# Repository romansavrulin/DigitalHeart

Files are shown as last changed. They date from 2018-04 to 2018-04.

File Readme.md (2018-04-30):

# RDC1-0009, Цифровое сердце

Это цифровое, светодиодное сердце будет отличным подарком девушке ко Дню Влюбленных, 8 Марта, или на День рождения.
21 светодиод расположены по периметру печатной платы в виде сердца. Все они управляются микроконтроллером ATmega328. В демонстрационном скетче прописаны несколько эффектов оживляющих сердце. Скетч загружается с помощью любого контроллера Arduino. Но главная изюминка это вибромоторчик от смартфона расположенный на тыльной стороне. Он создает эффект бьющегося в такт световым эффектам сердца. Скетч легко изменить, если вы придумаете новые световые эффекты и частоту стука сердца. 
На тыльной стороне сердца есть зарядное устройство для Li-ion аккумуляторов, которое будет подзаряжать ваше сердце через порт Mini USB. Схема зарядного устройства собрана на микросхеме MCP73831T. Схема включения стандартная из описания на микросхему.
Все детали проекта открыты для свободного использования. Проект созданный в KiCAD можно скачать в приложении. Программу скачивайте в разделе «Скетч – код программы».

## Внешний вид устройства

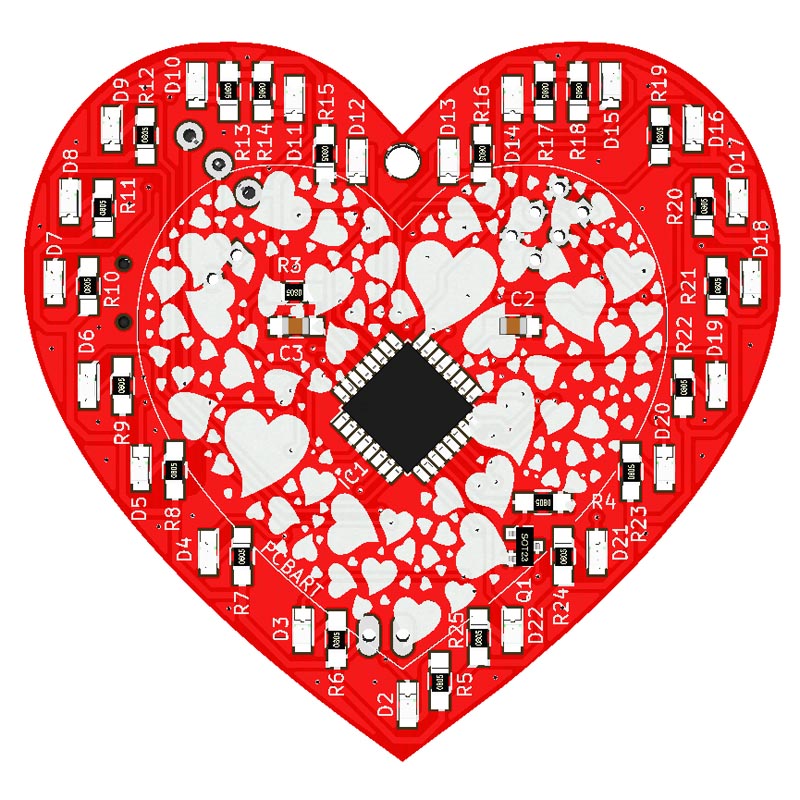
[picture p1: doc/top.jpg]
TOP


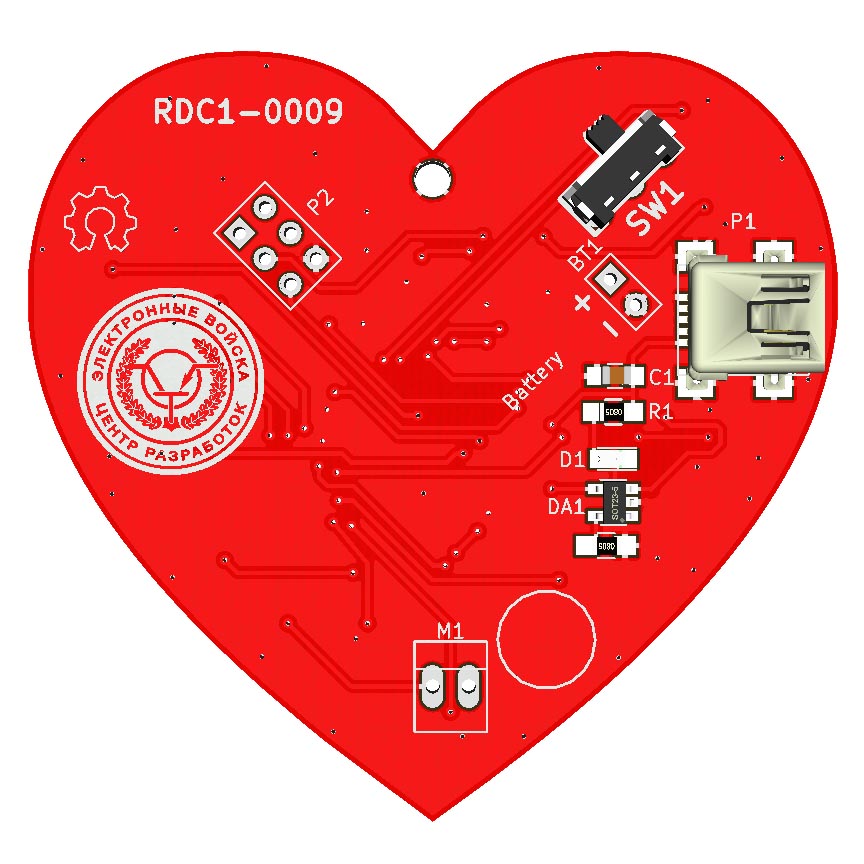
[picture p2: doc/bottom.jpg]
BOTTOM


## Технические параметры

Размер - 50 х 50 мм.
Источник питания – Li-Ion или Li-Pol аккумулятор 3,7В

## Programmer wiring

| Nano pins | NANO ISP PIN | Nano net | Target Net | Target Pin |
|-----|-----|-----|-----|----|
| D12 | 1 | MOSI | MISO | 1 |
| 5V  | 2 | 5V | 5V | 2 |
| D13 | 3 | SCK | SCK  | 3 |
| D11 | 4 | MISO | MOSI | 4 |
| D10 | N/A, USE D10 | TARGET_RST | RST | 5  |
| GND | 6 | GND | GND  | 6 |

## Troubleshooting

If you get slow effects, it's wrong FUSE configuration. Try to run 

```
"C:\Program Files (x86)\Arduino\hardware\tools\avr/bin/avrdude" "-CC:\Program Files (x86)\Arduino\hardware\tools\avr/etc/avrdude.conf" -v -patmega168p -cstk500v1 -PCOM4 -b19200 -U lfuse:w:0xE2:m
```

from console

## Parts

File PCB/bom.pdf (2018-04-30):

количество | позиция | наименование номенклатуры | код номенклатуры
22 | D1 - D22 | KPT-2012SURCK, Светодиод красный 150мКд SMD | 498825037
1 | P1 | MiniUSB-A, Розетка 5-контактная SMD на плату | 587420270
3 | C1, C2,C3 | Кер.ЧИП конд. 0.1 мкФ Y5V 50В,+80-20%, 0805 | 642412305
1 | SW1 | SS12F27, Переключатель движковый | 826042990
1 | R2 | 0.125Вт 0805 2 кОм, 5%, Чип резистор (SMD) | 811944944
22 | R1, R5-R25 | 0.125Вт 0805 360 Ом, 1%, Чип резистор (SMD) | 9000079475
2 | R3, R4 | 0.125Вт 0805 10 кОм, 1%, Чип резистор (SMD) | 9000079514
1 | IC1 | ATmega168PA-AU | 9000105081
1 | DA1 | MCP73831T | 9000161965
1 | V.Motor | VIBRATING-MOTOR | 9000313207
1 | Q1 | BSS138, Транзистор, N-канал | 919815894
1 | | Печатная плата rdc1-0009 h | 9000327321

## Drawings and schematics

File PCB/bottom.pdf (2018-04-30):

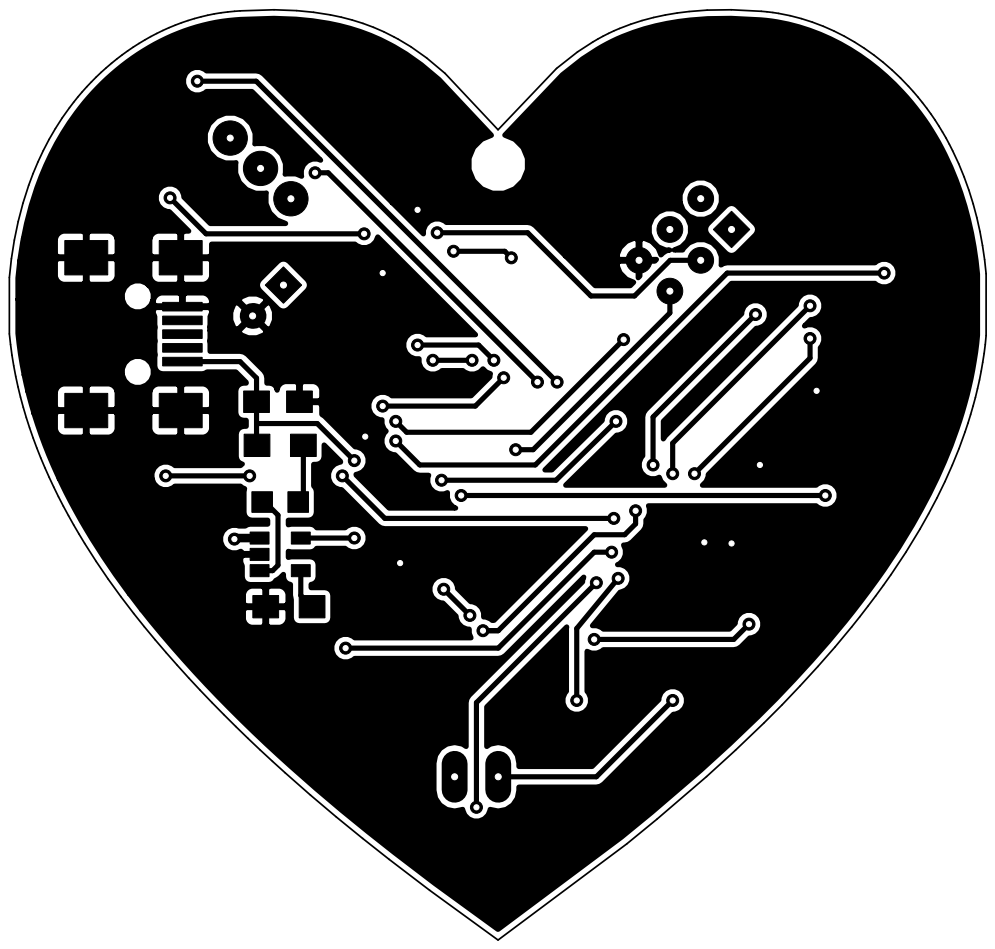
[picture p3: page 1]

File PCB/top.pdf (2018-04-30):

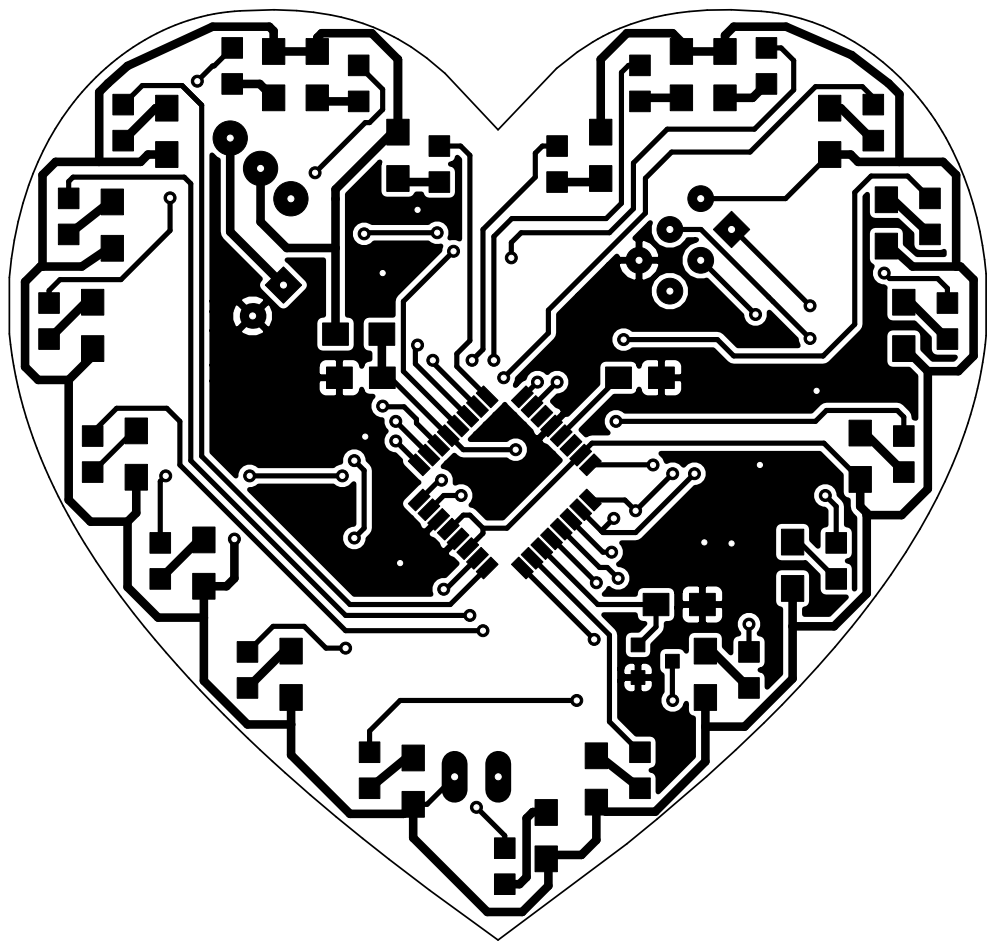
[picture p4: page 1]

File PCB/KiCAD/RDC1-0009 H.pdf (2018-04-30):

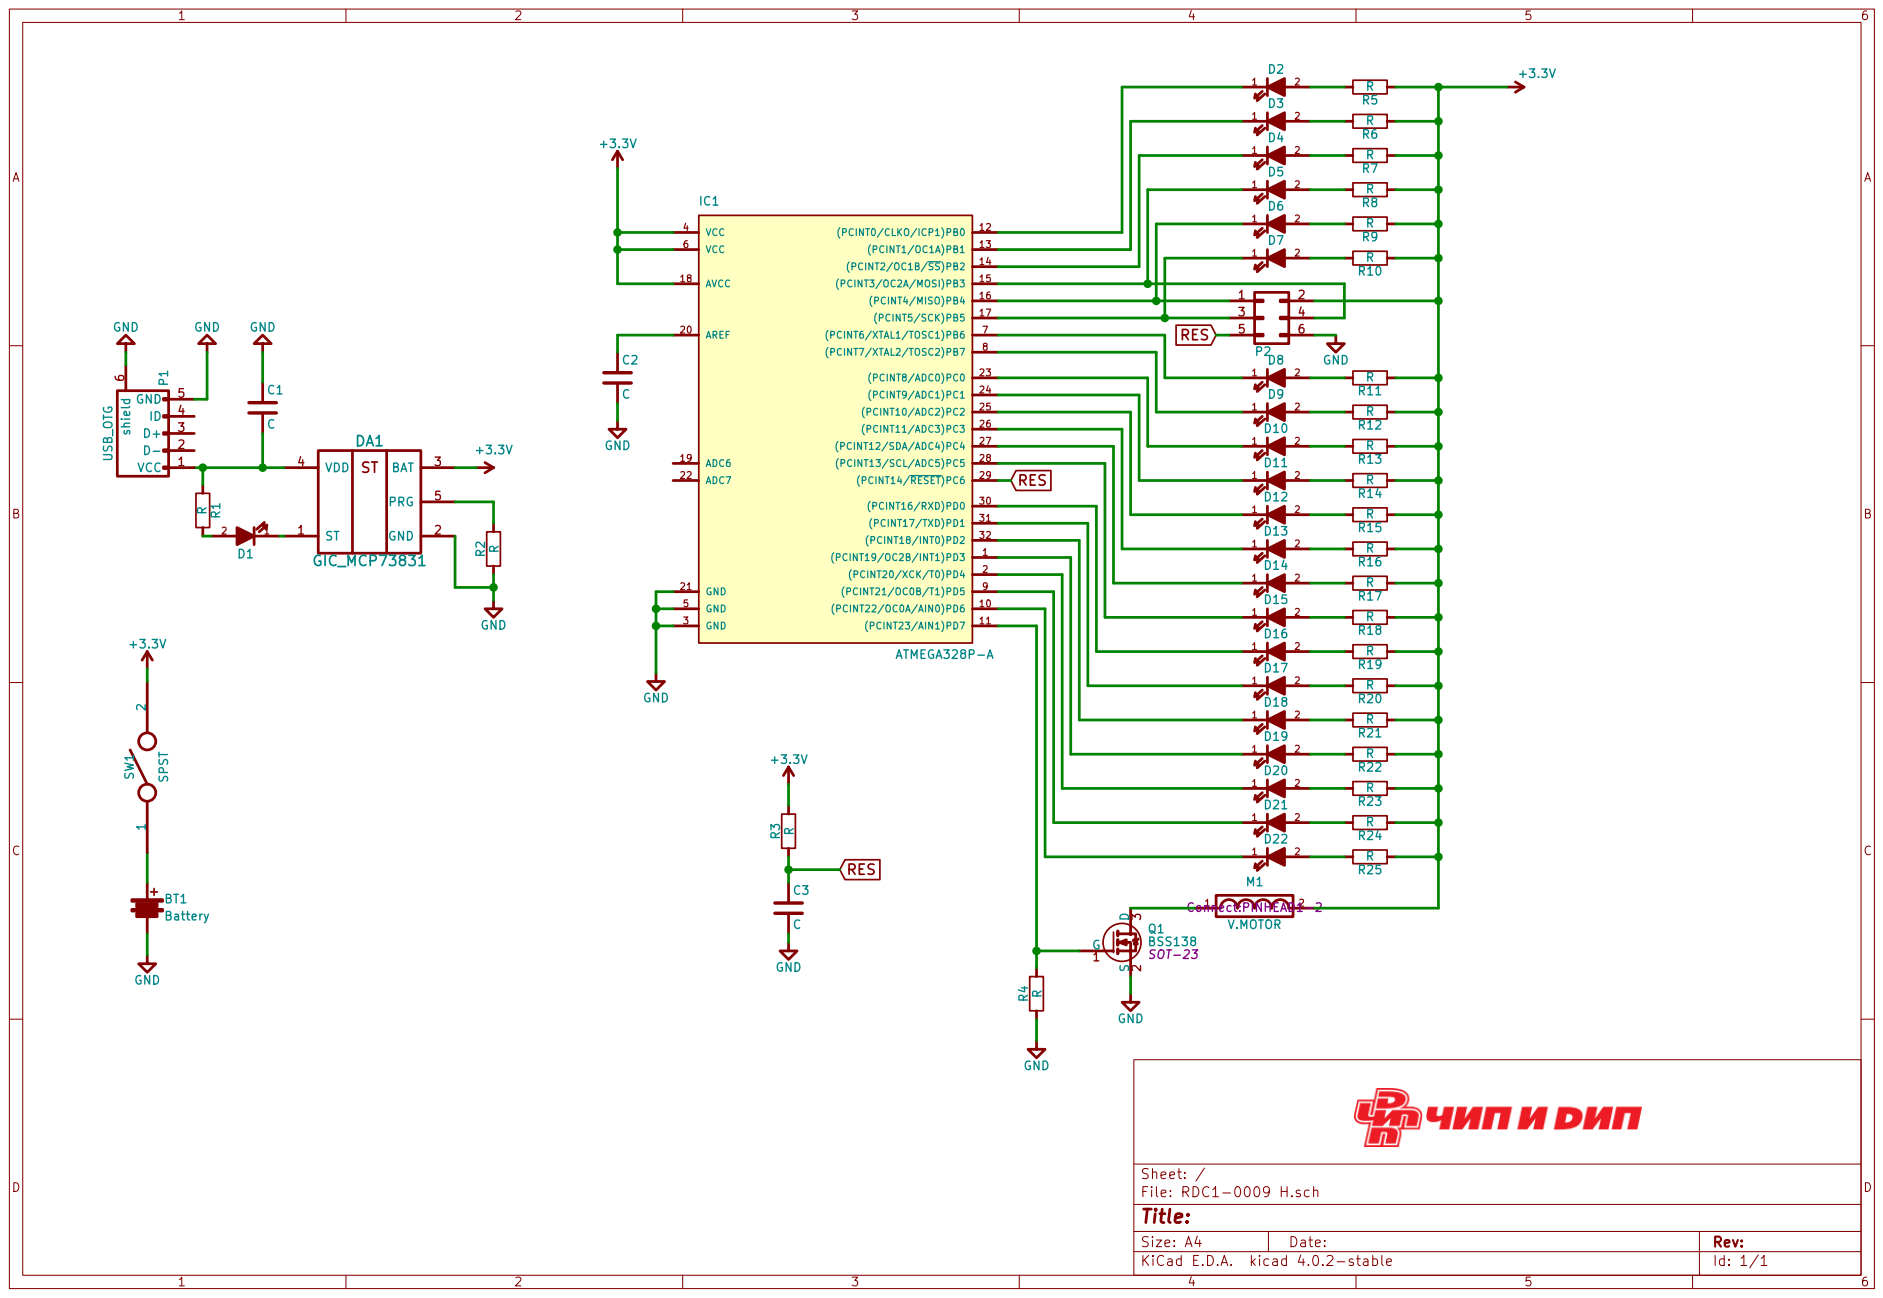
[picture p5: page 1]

Id: 1/1 Title: File: RDC1-0009 H.sch Sheet: /

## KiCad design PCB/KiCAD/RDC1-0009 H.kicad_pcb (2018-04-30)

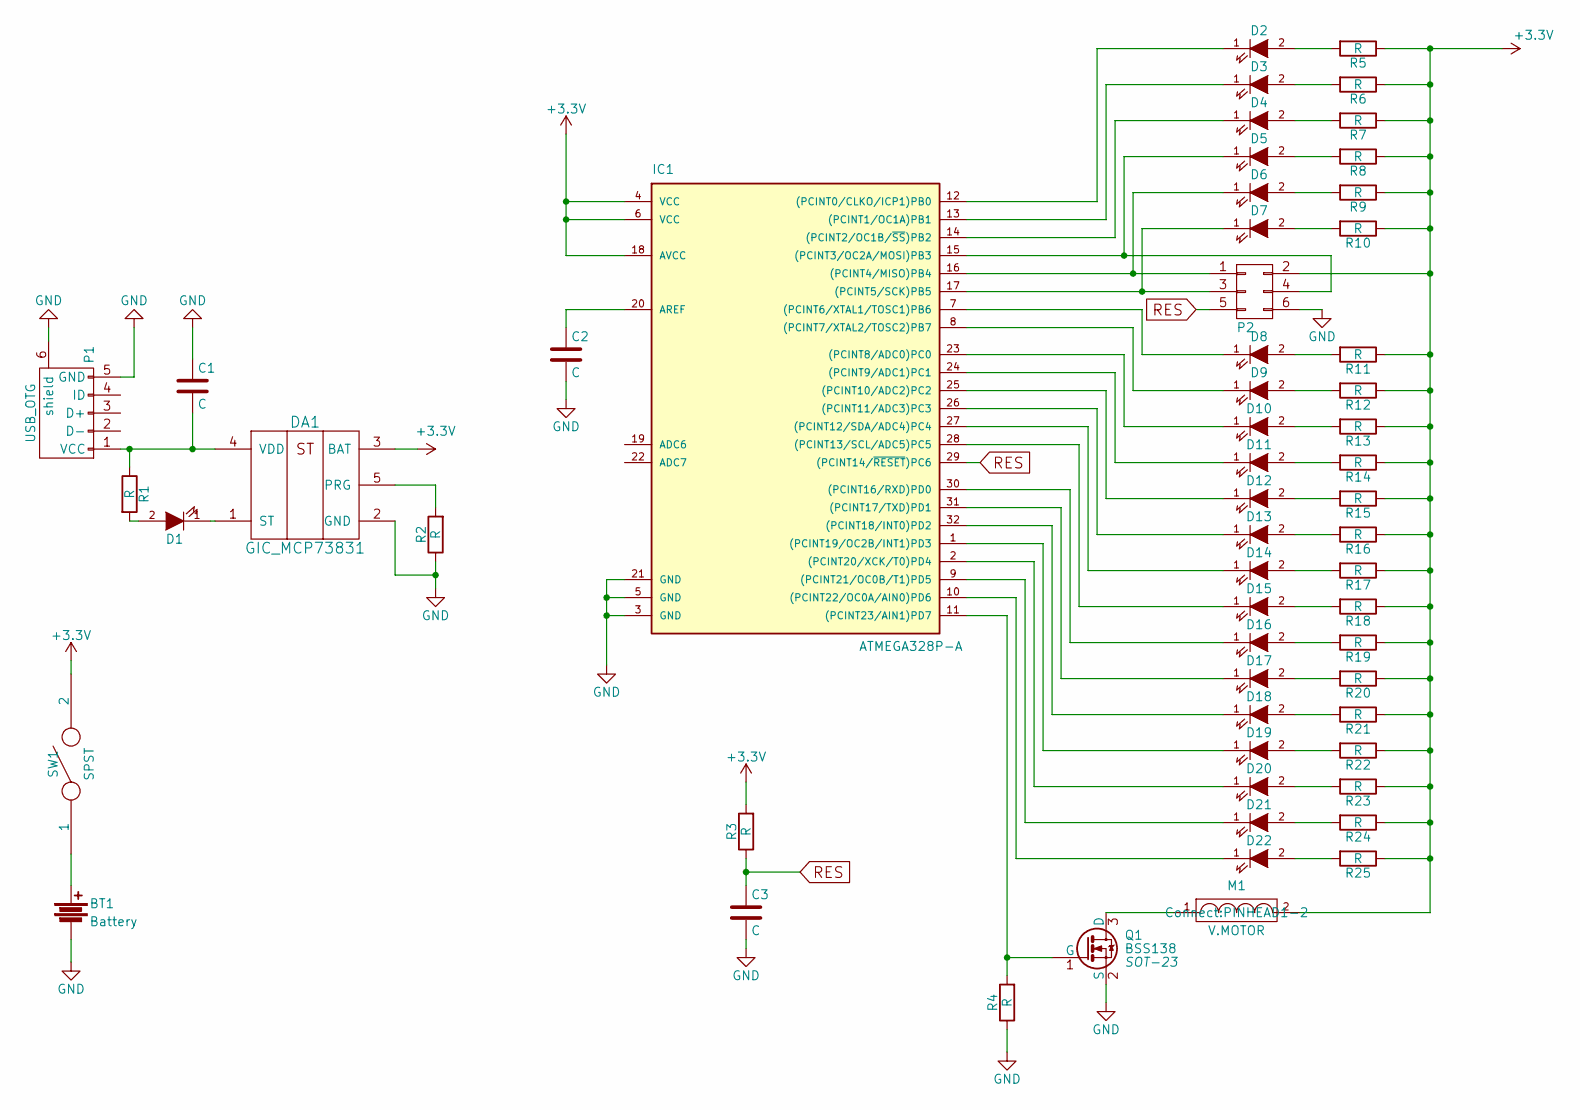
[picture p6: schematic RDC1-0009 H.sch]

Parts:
BT1: Battery; Pin_Header_Straight_1x02_mm
C1, C2, C3: C; C_0805_HandSoldering
D1, D2, D3, D4, D5, D6, D7, D8, D9, D10, D11, D12, D13, D14, D15, D16, D17, D18, D19, D20, D21, D22: LED; LED_0805
DA1: GIC_MCP73831; SOT-23-5_mm
IC1: ATMEGA328P-A; LQFP-32_7x7mm_Pitch0.8mm
M1: V.MOTOR; PINHEAD1-2
P1: USB_OTG; USB_Mini-B_mm
P2: CONN_02X03; Pin_Header_Straight_2x03_mm
Q1: BSS138; SOT-23
R1, R2, R3, R4, R5, R6, R7, R8, R9, R10, R11, R12, R13, R14, R15, R16, R17, R18, R19, R20, R21, R22, R23, R24, R25: R; R_0805_HandSoldering
SW1: SPST; SWITCH-mmp122-r

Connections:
+3V3: DA1.3 (BAT), IC1.4 (VCC), IC1.6 (VCC), IC1.18 (AVCC), M1.2, P2.2, R3.2, R5.1, R6.1, R7.1, R8.1, R9.1, R10.1, R11.1, R12.1, R13.1, R14.1, R15.1, R16.1, R17.1, R18.1, R19.1, R20.1, R21.1, R22.1, R23.1, R24.1, R25.1, SW1.2
GND: BT1.2, C1.1, C2.2, C3.2, DA1.2 (GND), IC1.3 (GND), IC1.5 (GND), IC1.21 (GND), P1.5 (GND), P1.6 (shield), P2.6, Q1.2 (S), R2.1, R4.1
unnamed: BT1.1, SW1.1
unnamed: C1.2, DA1.4 (VDD), P1.1 (VCC), R1.1
unnamed: C2.1, IC1.20 (AREF)
unnamed: D1.1 (K), DA1.1 (ST)
unnamed: D1.2 (A), R1.2
unnamed: D2.1 (K), IC1.12 ((PCINT0/CLKO/ICP1)PB0)
unnamed: D2.2 (A), R5.2
unnamed: D3.1 (K), IC1.13 ((PCINT1/OC1A)PB1)
unnamed: D3.2 (A), R6.2
unnamed: D4.1 (K), IC1.14 ((PCINT2/OC1B/~SS~)PB2)
unnamed: D4.2 (A), R7.2
unnamed: D5.1 (K), IC1.15 ((PCINT3/OC2A/MOSI)PB3), P2.4
unnamed: D5.2 (A), R8.2
unnamed: D6.1 (K), IC1.16 ((PCINT4/MISO)PB4), P2.1
unnamed: D6.2 (A), R9.2
unnamed: D7.1 (K), IC1.17 ((PCINT5/SCK)PB5), P2.3
unnamed: D7.2 (A), R10.2
unnamed: D8.1 (K), IC1.7 ((PCINT6/XTAL1/TOSC1)PB6)
unnamed: D8.2 (A), R11.2
unnamed: D9.1 (K), IC1.8 ((PCINT7/XTAL2/TOSC2)PB7)
unnamed: D9.2 (A), R12.2
unnamed: D10.1 (K), IC1.23 ((PCINT8/ADC0)PC0)
unnamed: D10.2 (A), R13.2
unnamed: D11.1 (K), IC1.24 ((PCINT9/ADC1)PC1)
unnamed: D11.2 (A), R14.2
unnamed: D12.1 (K), IC1.25 ((PCINT10/ADC2)PC2)
unnamed: D12.2 (A), R15.2
unnamed: D13.1 (K), IC1.26 ((PCINT11/ADC3)PC3)
unnamed: D13.2 (A), R16.2
unnamed: D14.1 (K), IC1.27 ((PCINT12/SDA/ADC4)PC4)
unnamed: D14.2 (A), R17.2
unnamed: D15.1 (K), IC1.28 ((PCINT13/SCL/ADC5)PC5)
unnamed: D15.2 (A), R18.2
unnamed: D16.1 (K), IC1.30 ((PCINT16/RXD)PD0)
unnamed: D16.2 (A), R19.2
unnamed: D17.1 (K), IC1.31 ((PCINT17/TXD)PD1)
unnamed: D17.2 (A), R20.2
unnamed: D18.1 (K), IC1.32 ((PCINT18/INT0)PD2)
unnamed: D18.2 (A), R21.2
unnamed: D19.1 (K), IC1.1 ((PCINT19/OC2B/INT1)PD3)
unnamed: D19.2 (A), R22.2
unnamed: D20.1 (K), IC1.2 ((PCINT20/XCK/T0)PD4)
unnamed: D20.2 (A), R23.2
unnamed: D21.1 (K), IC1.9 ((PCINT21/OC0B/T1)PD5)
unnamed: D21.2 (A), R24.2
unnamed: D22.1 (K), IC1.10 ((PCINT22/OC0A/AIN0)PD6)
unnamed: D22.2 (A), R25.2
unnamed: DA1.5 (PRG), R2.2
unnamed: IC1.11 ((PCINT23/AIN1)PD7), Q1.1 (G), R4.2
unnamed: M1.1, Q1.3 (D)
RES: C3.1, IC1.29 ((PCINT14/~RESET~)PC6), P2.5, R3.1

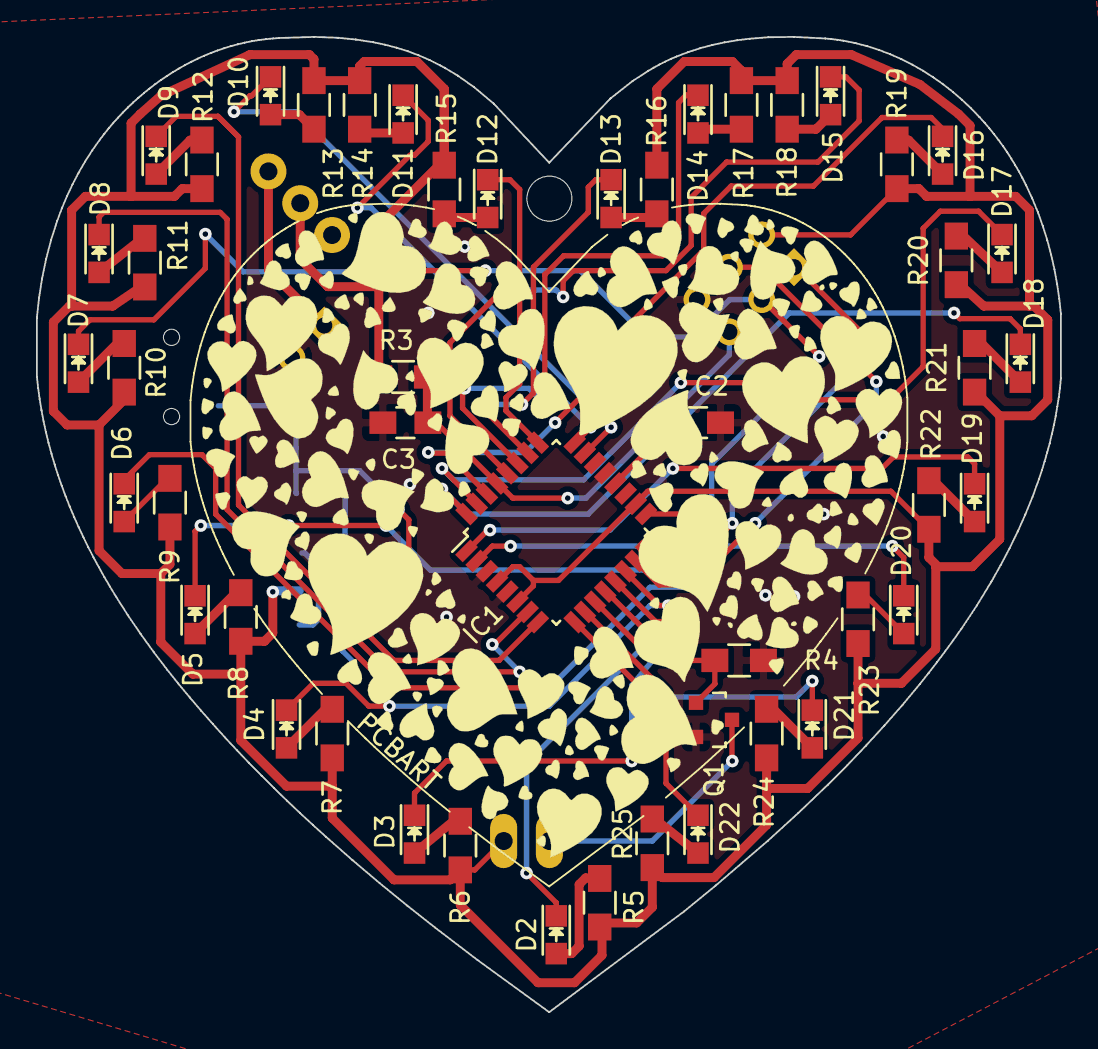
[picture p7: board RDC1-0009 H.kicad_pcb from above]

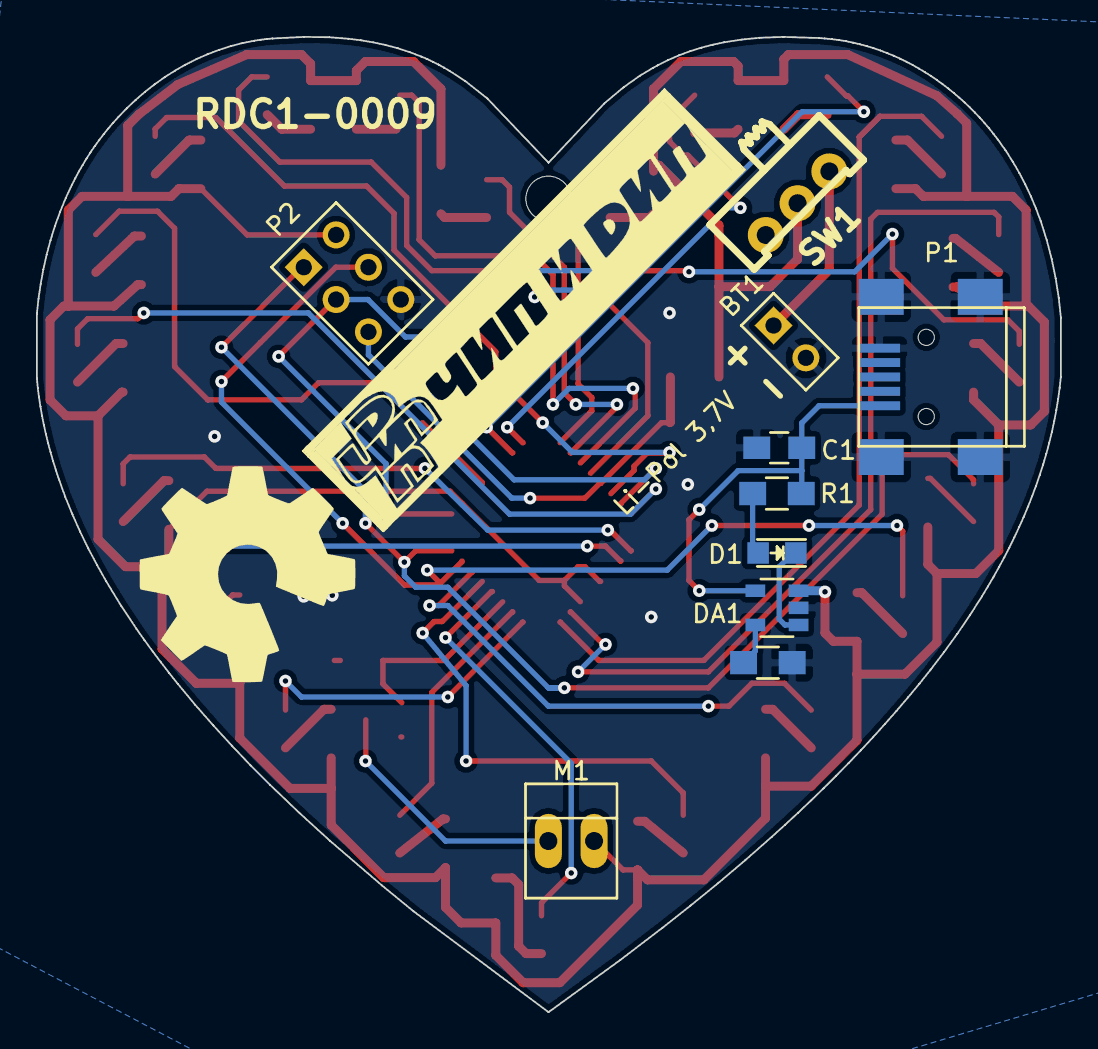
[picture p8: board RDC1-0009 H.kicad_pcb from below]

Board: 2 copper layers, 56.9 x 54.2 mm, 58 parts (10 on the bottom side), 53 nets.

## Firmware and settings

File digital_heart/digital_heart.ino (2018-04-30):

void setup()
{ 
  DDRB = 0xFF;
  PORTB = 0xFF;

  DDRC = 0x3F;
  PORTC = 0x3F;

  DDRD = 0xFF;
  PORTD = 0x7F;
}
//------------------------------------------------------
void loop()
{ 
  for (byte j = 0; j < 3; j++)
    Effect_1();
  for (byte j = 0; j < 3; j++)
    Effect_2();
  for (byte j = 0; j < 3; j++)
    Effect_3();
  for (byte j = 0; j < 3; j++)
    Effect_4();
  for (byte j = 0; j < 3; j++)
    Effect_5();
    
  Effect_6();
  
  for (byte j = 0; j < 3; j++)
  {
    for (unsigned int i = 0; i < 30000; i++)
    Effect_7();
  }
  
  for (byte j = 0; j < 3; j++)
    Effect_8();
  for (byte j = 0; j < 3; j++)
    Effect_9();
  for (byte j = 0; j < 3; j++)
    Effect_10();
  for (byte j = 0; j < 3; j++)
    Effect_11();
}
//------------------------------------------------------------
//Р­С„С„РµРєС‚ 1
void Effect_1()
{
  for (byte j = 0; j <= 7; j++)
  {
    PORTB &= ~(1 << j);
    delay(75);
  }

  for (byte j = 0; j <= 5; j++)
  {
    PORTC &= ~(1 << j);
    delay(75);
  }

  for (byte j = 0; j < 7; j++)
  {
    PORTD &= ~(1 << j);
    delay(75);
  }

  for (byte j = 0; j < 2; j++)
  {
    All_OFF();
    delay(150);
    All_ON();
    delay(150);
  }

  All_OFF();
}
//---------------------------------------------------------
//Р­С„С„РµРєС‚ 2
void Effect_2()
{
  for (byte j = 0; j <= 7; j++)
  {
    PORTB &= ~(1 << j);
    delay(75);
    PORTB |= (1 << j);
  }

  for (byte j = 0; j <= 5; j++)
  {
    PORTC &= ~(1 << j);
    delay(75);
    PORTC |= (1 << j);
  }

  for (byte j = 0; j < 7; j++)
  {
    PORTD &= ~(1 << j);
    delay(75);
    PORTD |= (1 << j);
  }
}
//---------------------------------------------------------
//Р­С„С„РµРєС‚ 3
void Effect_3()
{
  byte Value;
  boolean ClearFlag;
    
  //РІРєР»СЋС‡РµРЅРёРµ
  while ((PORTB != 0) || ((PORTC & 0x3F) != 0) || ((PORTD & 0x7F) != 0))
  {
    //PORTB
    if (PORTB != 0)
    {
      Value = random(0, 8);
      ClearFlag = false;
      if ((PORTB & (1 << Value)) != (1 << Value))
      {
        for (byte j = Value; j <= 7; j++)
        {
          if ((PORTB & (1 << j)) == (1 << j))
          {
            PORTB &= ~(1 << j);
            ClearFlag = true;
            break;
          }
        }

        if (!ClearFlag)
        {
          for (byte j = 0; j < Value; j++)
          {
            if ((PORTB & (1 << j)) == (1 << j))
            {
              PORTB &= ~(1 << j);
              ClearFlag = true;
              break;
            }
          }
        }
      }

      else
      {
        PORTB &= ~(1 << Value);
      }
    }
    //PORTC
    if ((PORTC & 0x3F) != 0)
    {
      Value = random(0, 6);
      ClearFlag = false;
      if ((PORTC & (1 << Value)) != (1 << Value))
      {
        for (byte j = Value; j <= 7; j++)
        {
          if ((PORTC & (1 << j)) == (1 << j))
          {
            PORTC &= ~(1 << j);
            ClearFlag = true;
            break;
          }
        }

        if (!ClearFlag)
        {
          for (byte j = 0; j < Value; j++)
          {
            if ((PORTC & (1 << j)) == (1 << j))
            {
              PORTC &= ~(1 << j);
              ClearFlag = true;
              break;
            }
          }
        }
      }

      else
      {
        PORTC &= ~(1 << Value);
      }
    }
    //PORTD
    if ((PORTD & 0x7F) != 0)
    {
      Value = random(0, 7);
      ClearFlag = false;
      if ((PORTD & (1 << Value)) != (1 << Value))
      {
        for (byte j = Value; j <= 7; j++)
        {
          if ((PORTD & (1 << j)) == (1 << j))
          {
            PORTD &= ~(1 << j);
            ClearFlag = true;
            break;
          }
        }

        if (!ClearFlag)
        {
          for (byte j = 0; j < Value; j++)
          {
            if ((PORTD & (1 << j)) == (1 << j))
            {
              PORTD &= ~(1 << j);
              ClearFlag = true;
              break;
            }
          }
        }
      }

      else
      {
        PORTD &= ~(1 << Value);
      }
    }

      delay(150);
  }
    
  delay(1000);

  //РІС‹РєР»СЋС‡РµРЅРёРµ
  while ((PORTB != 0xFF) || ((PORTC & 0x3F) != 0x3F) || ((PORTD & 0x7F) != 0x7F))
  {
    //PORTB
    if (PORTB != 0xFF)
    {      
      Value = random(0, 8);
      ClearFlag = false;
      if ((PORTB & (1 << Value)) == (1 << Value))
      {
        for (byte j = Value; j <= 7; j++)
        {
          if ((PORTB & (1 << j)) != (1 << j))
          {
            PORTB |= (1 << j);
            ClearFlag = true;
            break;
          }
        }

        if (!ClearFlag)
        {
          for (byte j = 0; j < Value; j++)
          {
            if ((PORTB & (1 << j)) != (1 << j))
            {
              PORTB |= (1 << j);
              ClearFlag = true;
              break;
            }
          }
        }
      }

      else
      {
        PORTB |= (1 << Value);
      }
    }
    //PORTC
    if ((PORTC & 0x3F) != 0x3F)
    {
      Value = random(0, 6);
      ClearFlag = false;
      if ((PORTC & (1 << Value)) == (1 << Value))
      {
        for (byte j = Value; j <= 7; j++)
        {
          if ((PORTC & (1 << j)) != (1 << j))
          {
            PORTC |= (1 << j);
            ClearFlag = true;
            break;
          }
        }

        if (!ClearFlag)
        {
          for (byte j = 0; j < Value; j++)
          {
            if ((PORTC & (1 << j)) != (1 << j))
            {
              PORTC |= (1 << j);
              ClearFlag = true;
              break;
            }
          }
        }
      }

      else
      {
        PORTC |= (1 << Value);
      }
    }
    //PORTD
    if ((PORTD & 0x7F) != 0x7F)
    {
      Value = random(0, 7);
      ClearFlag = false;
      if ((PORTD & (1 << Value)) == (1 << Value))
      {
        for (byte j = Value; j < 7; j++)
        {
          if ((PORTD & (1 << j)) != (1 << j))
          {
            PORTD |= (1 << j);
            ClearFlag = true;
            break;
          }
        }

        if (!ClearFlag)
        {
          for (byte j = 0; j < Value; j++)
          {
            if ((PORTD & (1 << j)) != (1 << j))
            {
              PORTD |= (1 << j);
              ClearFlag = true;
              break;
            }
          }
        }
      }

      else
      {
        PORTD |= (1 << Value);
      }
    }

    delay(150);
  }
    
  delay(1000);
}
//------------------------------------------------------------
//Р­С„С„РµРєС‚ 4
void Effect_4()
{ 
  All_ON();
  delay(750);
  All_OFF();
  delay(750); 
}
//---------------------------------------------------------
//Р­С„С„РµРєС‚ 5
void Effect_5()
{
  PORTB &= ~(1 << 0);
  delay(75);
  
  for (byte i = 1; i <= 7; i++)
  {
    PORTB &= ~(1 << i);
    PORTD &= ~(1 << (7 - i));
    delay(75);
  }

  for (byte i = 0; i <= 2; i++)
  {
    PORTC &= ~((1 << i) | (1 << (5 - i)));
    delay(75);
  }
  
  delay(750);

  for (byte i = 3; i <= 5; i++)
  {
    PORTC |= ((1 << (5 - i)) | (1 << i));
    delay(75);
  }

  for (byte i = 7; i >= 1; i--)
  {
    PORTB |= (1 << i);
    PORTD |= (1 << (7 - i));
    delay(75);
  }

  PORTB |= (1 << 0);
  delay(75);

  delay(750);
}
//---------------------------------------------------------
//Р­С„С„РµРєС‚ 6
void Effect_6()
{
  const unsigned int DotUnit = 100;
  const unsigned int DashUnit = 3 * DotUnit;
  const unsigned int WordSpace = 7 * DotUnit;

  //РЇ
  for (byte i = 0; i < 2; i++)
  {
    //.
    All_ON();
    delay(DotUnit);
    All_OFF();
    delay(DotUnit);
    //-
    All_ON();
    delay(DashUnit);
    All_OFF();
    delay(DotUnit);
  }
  //РїР°СѓР•Р° РјРµР¶РґСѓ СЃР»РѕРІР°РјРё
  delay(WordSpace - DotUnit);

  //С‚РµР±СЏ
  //С‚
  // -
  All_ON();
  delay(DashUnit);
  All_OFF();
  //РїР°СѓР•Р° РјРµР¶РґСѓ Р±СѓРєРІР°РјРё
  delay(DashUnit);
  //Рµ
  //.
  All_ON();
  delay(DotUnit);
  All_OFF();
  //РїР°СѓР•Р° РјРµР¶РґСѓ Р±СѓРєРІР°РјРё
  delay(DashUnit);
  //Р±
  //-
  All_ON();
  delay(DashUnit);
  All_OFF();
  delay(DotUnit);
  for (byte i = 0; i < 3; i++)
  {
    //.
    All_ON();
    delay(DotUnit);
    All_OFF();
    delay(DotUnit);
  }
  //РїР°СѓР•Р° РјРµР¶РґСѓ Р±СѓРєРІР°РјРё
  delay(DashUnit - DotUnit);

  //СЏ
  for (byte i = 0; i < 2; i++)
  {
    //.
    All_ON();
    delay(DotUnit);
    All_OFF();
    delay(DotUnit);
    //-
    All_ON();
    delay(DashUnit);
    All_OFF();
    delay(DotUnit);
  }
  //РїР°СѓР•Р° РјРµР¶РґСѓ СЃР»РѕРІР°РјРё
  delay(WordSpace - DotUnit);

  //Р»СЋР±Р»СЋ
  //Р»
  //.
  All_ON();
  delay(DotUnit);
  All_OFF();
  delay(DotUnit);
  //-
  All_ON();
  delay(DashUnit);
  All_OFF();
  delay(DotUnit);
  for (byte i = 0; i < 2; i++)
  {
    //.
    All_ON();
    delay(DotUnit);
    All_OFF();
    delay(DotUnit);
  }
  //РїР°СѓР•Р° РјРµР¶РґСѓ Р±СѓРєРІР°РјРё
  delay(DashUnit - DotUnit);
  //СЋ
  for (byte i = 0; i < 2; i++)
  {
    //.
    All_ON();
    delay(DotUnit);
    All_OFF();
    delay(DotUnit);
  }
  for (byte i = 0; i < 2; i++)
  {
    //-
    All_ON();
    delay(DashUnit);
    All_OFF();
    delay(DotUnit);
  }
  //РїР°СѓР•Р° РјРµР¶РґСѓ Р±СѓРєРІР°РјРё
  delay(DashUnit - DotUnit);
  //Р±
  //-
  All_ON();
  delay(DashUnit);
  All_OFF();
  delay(DotUnit);
  for (byte i = 0; i < 3; i++)
  {
    //.
    All_ON();
    delay(DotUnit);
    All_OFF();
    delay(DotUnit);
  }
  //РїР°СѓР•Р° РјРµР¶РґСѓ Р±СѓРєРІР°РјРё
  delay(DashUnit - DotUnit);
  //Р»
  //.
  All_ON();
  delay(DotUnit);
  All_OFF();
  delay(DotUnit);
  //-
  All_ON();
  delay(DashUnit);
  All_OFF();
  delay(DotUnit);
  for (byte i = 0; i < 2; i++)
  {
    //.
    All_ON();
    delay(DotUnit);
    All_OFF();
    delay(DotUnit);
  }
  //РїР°СѓР•Р° РјРµР¶РґСѓ Р±СѓРєРІР°РјРё
  delay(DashUnit - DotUnit);
  //СЋ
  for (byte i = 0; i < 2; i++)
  {
    //.
    All_ON();
    delay(DotUnit);
    All_OFF();
    delay(DotUnit);
  }
  for (byte i = 0; i < 2; i++)
  {
    //-
    All_ON();
    delay(DashUnit);
    All_OFF();
    delay(DotUnit);
  }
  //РїР°СѓР•Р° РјРµР¶РґСѓ СЃР»РѕРІР°РјРё
  delay(WordSpace - DotUnit);
}
//---------------------------------------------------------
//Р­С„С„РµРєС‚ 7
void Effect_7()
{
  const byte BrightnessRate = 100;
  const byte Period = 100;
  static byte PeriodCounter = 0;
  static boolean State = false;
  static byte DutyCycle = 0;
  static byte DutyCycleCounter = 0;
  
  delayMicroseconds(200);

  DutyCycleCounter++;
  
  if (DutyCycleCounter == BrightnessRate)
  {
    if (!State)
    {
      DutyCycle++;
      if (DutyCycle == PeriodCounter)
      {
        State = true;
      }
    }
  
    else
    {
      DutyCycle--;
      if (DutyCycle == 0)
      {
        State = false;
      }
    }

    DutyCycleCounter = 0;
  }

  if (PeriodCounter < DutyCycle)
    All_ON();
  else
    All_OFF();
  
  PeriodCounter++;

  if (PeriodCounter == Period)
    PeriodCounter = 0;
}
//----------------------------------------------
//Р­С„С„РµРєС‚ 8
void Effect_8() 
{
  All_OFF();
  PORTB &= ~((1 << 0) | (1 << 1) | (1 << 3) | (1 << 5) | (1 << 7));
  PORTC &= ~((1 << 1) | (1 << 4));
  PORTD &= ~((1 << 0) | (1 << 2) | (1 << 4) | (1 << 6));
  delay(300);
  All_OFF();
  PORTB &= ~((1 << 0) | (1 << 2) | (1 << 4) | (1 << 6));
  PORTC &= ~((1 << 0) | (1 << 2) | (1 << 3) | (1 << 5));
  PORTD &= ~((1 << 1) | (1 << 3) | (1 << 5));
  delay(300);
}
//----------------------------------------------
//Р­С„С„РµРєС‚ 9
void Effect_9() 
{
  All_OFF();
  PORTB = 0;
  PORTC &= ~((1 << 0) | (1 << 1) | (1 << 2));
  delay(300);
  All_OFF();
  PORTB &= ~(1 << 0);
  PORTC &= ~((1 << 3) | (1 << 4) | (1 << 5));
  PORTD = 0;
  delay(300);
}
//----------------------------------------------
//Р­С„С„РµРєС‚ 10
void Effect_10()
{  
  PORTB &= ~(1 << 0);

  for (byte i = 1; i <= 7; i++)
  {
    PORTB &= ~(1 << i);
    if (i < 4)
      PORTC |= (1 << (i + 2));
    else
      PORTD |= (1 << (i - 4));
    delay(150);    
  }

  for (byte i = 0; i <= 2; i++)
  {
    PORTC &= ~(1 << i);
    PORTD |= (1 << (i + 4));
    delay(150);    
  }

  for (byte i = 7; i >= 1; i--)
  {
    PORTD &= ~(1 << (i - 1));
    if (i > 4)
      PORTC |= (1 << (i - 5));
    else
      PORTB |= (1 << (i + 3));
    delay(150);
  }

  for (byte i = 5; i >= 3; i--)
  {
    PORTC &= ~(1 << i);
    PORTB |= (1 << (i - 2));
    delay(150);    
  }
}
//----------------------------------------------
//Р­С„С„РµРєС‚ 11
void Effect_11()
{
  PORTB &= ~(1 << 0);
  
  for (byte i = 7; i >= 1; i--)
  {
    PORTD &= ~(1 << (i - 1));
    if (i > 4)
      PORTC &= ~(1 << (i - 5));
    else
      PORTB &= ~(1 << (i + 3));
    delay(150);
  }

  for (byte i = 5; i >= 3; i--)
  {
    PORTC &= ~(1 << i);
    PORTB &= ~(1 << (i - 2));
    delay(150);    
  }

  for (byte i = 1; i <= 7; i++)
  {
    PORTB |= (1 << i);
    if (i < 4)
      PORTC |= (1 << (i + 2));
    else
      PORTD |= (1 << (i - 4));
    delay(150);    
  }

  for (byte i = 0; i <= 2; i++)
  {
    PORTC |= (1 << i);
    PORTD |= (1 << (i + 4));
    delay(150);    
  }

  PORTB |= (1 << 0);
  delay(150);
}
//----------------------------------------------
void All_ON()
{
  PORTB = 0;
  PORTC = 0;
  PORTD = 0x80;
}
//----------------------------------------------
void All_OFF()
{
  PORTB = 0xFF;
  PORTC = 0x3F;
  PORTD = 0x7F;
}

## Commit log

2018-04-30 Add PCB related stuff
    [RDC1-0009 H-B.Cu.gbr, RDC1-0009 H-B.Mask.gbr, RDC1-0009 H-B.SilkS.gbr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]
2018-04-30 fix fuses
